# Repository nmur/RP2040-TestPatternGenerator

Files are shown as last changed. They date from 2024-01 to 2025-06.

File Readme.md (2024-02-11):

# RP2040-TestPatternGenerator

This is a simple test pattern generator that runs on the RP2040 microcontroller. It uses the [PicoVGA cmake](https://github.com/codaris/picovga-cmake) library for outputting a 15kHz 240p RGBS signal via a VGA connector. This tool is aimed to be used for rudimentary tests for checking basic CRT TV functionality, not for accurate calibration.  

Its main features are:  
- **Cheap**: Approximately <$15 USD in parts, less if you already have some components or if you want to make a few.
- **Accessible**: Open source. Soldering is easy enough even for a first timer.
- **Small**: Roughly 2x2"/50x50mm in size.
- **Fast**: Boots and changes patterns instantly.
- **Portable**: Very low power draw, works with a powerbank.

[](https://github.com/nmur/RP2040-TestPatternGenerator/assets/8315014/7c5d83b8-fa1e-4127-8eaf-c0302f727538)[](https://github.com/nmur/RP2040-TestPatternGenerator/assets/8315014/ee1879ff-74e5-49d6-872a-809746e85480)

## Limitations

This program can only output colours in the RGB332 space, so each of the three colour channels (Red, Green, and Blue) are represented by 3, 3, and 2 bits, respectively. More information can be found [here](https://github.com/nmur/RP2040-TestPatternGenerator/wiki/Limitations).

## Getting Started

1. [Obtain all the components and assemble the device](https://github.com/nmur/RP2040-TestPatternGenerator/wiki/Assembly).
2. Download the [latest firmware](https://github.com/nmur/RP2040-TestPatternGenerator/releases).
3. Hold the BOOT button on the RP2040 device and connect it to your PC. A file browser window for the device should appear.
4. Drag and drop the `RP2040-TestPatternGenerator.uf2` file onto the device. It should automatically close when completed.

## How to Use

- [Connect the device to your TV](https://github.com/nmur/RP2040-TestPatternGenerator/wiki/Frequently-Asked-Questions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), and connect a USB-C cable for power.
- Press the connected button to cycle through patterns.
- To flash a newer firmware, follow the same firmware installation steps from the [Getting Started](https://github.com/nmur/RP2040-TestPatternGenerator/tree/main?tab=readme-ov-file#getting-started) section. Once the device is installed in an enclosure and the BOOT button is inaccessable, connect the device to your computer, hold the same button for 3 seconds and release. The device will reboot into flash mode.

## Building

1. Generate the make files by running CMake:
~~~
cmake .
~~~

2. Build the project:
~~~
make
~~~

## Acknowledgements

- Miroslav Nemecek (Panda38@seznam.cz) for their [PicoVGA library](https://github.com/Panda381/PicoVGA)
- Wayne Venables (codaris) for their [PicoVGA fork](https://github.com/codaris/picovga-cmake)
- Turi Scandurra (TuriSc) for their [RP2040-Button library](https://github.com/TuriSc/RP2040-Button)

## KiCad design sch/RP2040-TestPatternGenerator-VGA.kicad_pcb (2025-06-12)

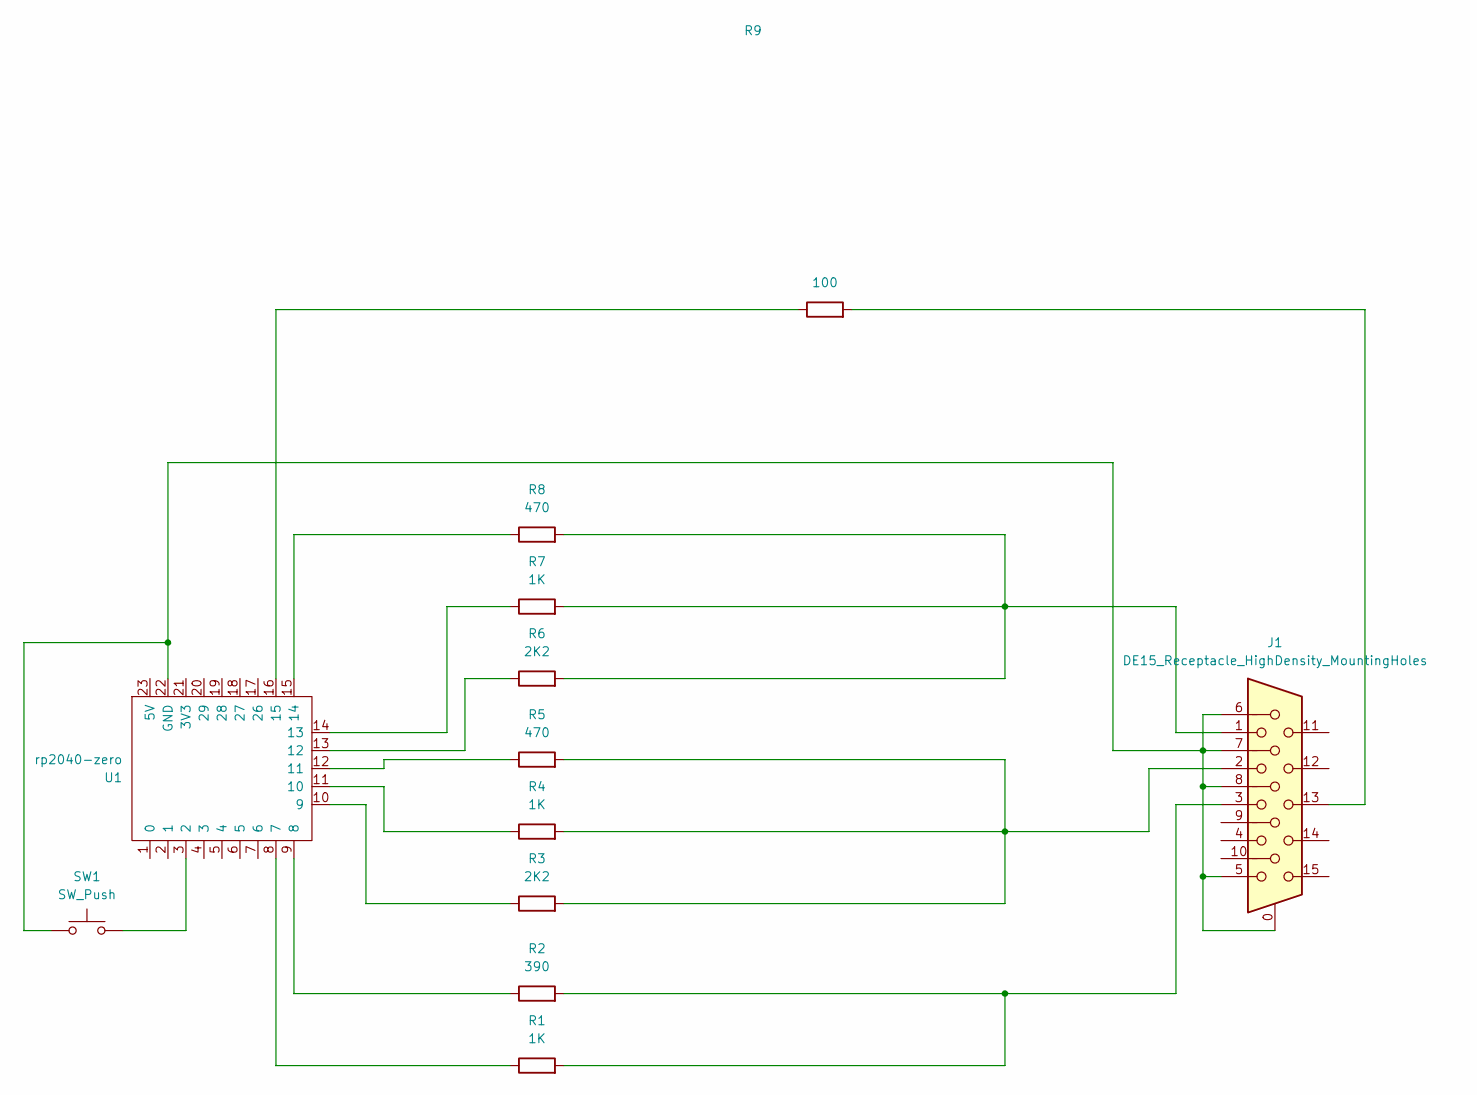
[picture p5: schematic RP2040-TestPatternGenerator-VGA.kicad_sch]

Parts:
J1: DE15_Receptacle_HighDensity_MountingHoles; DSUB-15-HD_Female_Horizontal_P2.29x1.98mm_EdgePinOffset3.03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
R1, R4, R7: 1K; R_Axial_DIN0207_L6.3mm_D2.5mm_P10.16mm_Horizontal
R2: 390; R_Axial_DIN0207_L6.3mm_D2.5mm_P10.16mm_Horizontal
R3, R6: 2K2; R_Axial_DIN0207_L6.3mm_D2.5mm_P10.16mm_Horizontal
R5, R8: 470; R_Axial_DIN0207_L6.3mm_D2.5mm_P10.16mm_Horizontal
R9: 100; R_Axial_DIN0207_L6.3mm_D2.5mm_P10.16mm_Horizontal
SW1: SW_Push; SW_Tactile_SPST_Angled_PTS645Vx58-2LFS
U1: rp2040-zero; rp2040-zero-smd

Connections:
unnamed 0: J1.1, R6.2, R7.2, R8.2; also elsewhere on the board
unnamed 1: J1.2, R3.2, R4.2, R5.2; also elsewhere on the board
unnamed 2: J1.3, R1.2, R2.2; also elsewhere on the board
unnamed 3: J1.13, R9.2; also elsewhere on the board
unnamed: SW1.2, U1.3 (2)
unnamed: R1.1, U1.8 (7)
unnamed: R2.1, U1.9 (8)
unnamed: R3.1, U1.10 (9)
unnamed: R4.1, U1.11 (10)
unnamed: R5.1, U1.12 (11)
unnamed: R6.1, U1.13 (12)
unnamed: R7.1, U1.14 (13)
unnamed: R8.1, U1.15 (14)
unnamed: R9.1, U1.16 (15)
unnamed 14: J1.0, J1.5, J1.6, J1.7, J1.8, SW1.1, U1.22 (GND); also elsewhere on the board

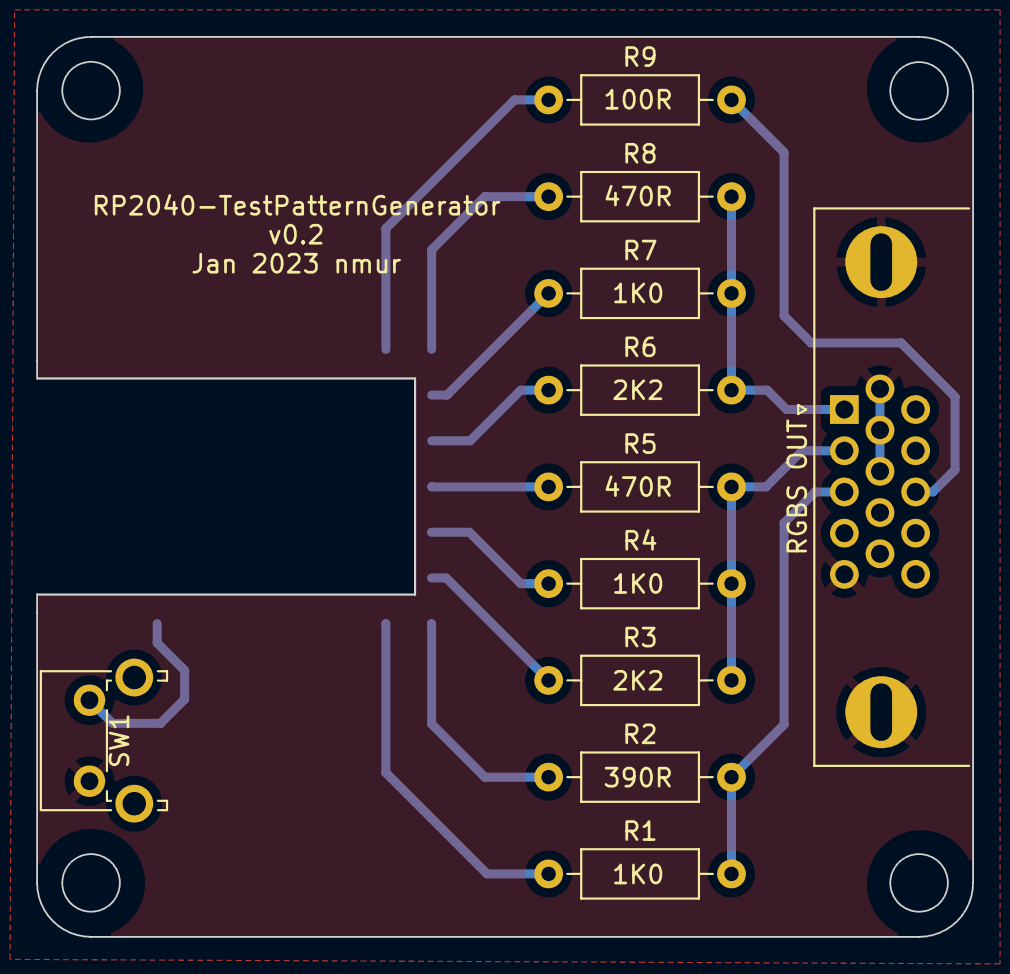
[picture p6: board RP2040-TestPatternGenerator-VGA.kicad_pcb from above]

Board: 2 copper layers, 52.0 x 50.0 mm, 12 parts (1 on the bottom side), 15 nets.

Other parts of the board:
RGBS OUT: DE15_Receptacle_HighDensity_MountingHoles; DSUB-15-HD_Female_Horizontal_P2.29x1.98mm_EdgePinOffset3.03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

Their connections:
unnamed 0: RGBS OUT.1; also elsewhere on the board
unnamed 1: RGBS OUT.2; also elsewhere on the board
unnamed 2: RGBS OUT.3; also elsewhere on the board
unnamed 3: RGBS OUT.13; also elsewhere on the board
unnamed 14: RGBS OUT.0, RGBS OUT.5, RGBS OUT.6, RGBS OUT.7, RGBS OUT.8; also elsewhere on the board

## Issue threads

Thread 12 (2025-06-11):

Schematic and brd files

eimparas, 2025-06-11:
While looking at this project, i failed to spot any `.sch` and .`brd` files (or a pdf could do) for the schematic of this very noice project.  Only the gerber files are uploaded.

Was this intentional ie the creator does not want schematics / board out there or they are simply forgoten?

nmur, 2025-06-12:
Hey, yeah this was an oversight and I likely just forgot to upload the schematic files themselves. He's a screenshot but I'll upload the kicad files too

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

eimparas, 2025-06-12:
Thanks for the immediate response!

I thought so it would be a oversight! Have a nice day.

Closed 2025-06-12.

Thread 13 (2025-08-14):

The razio under resistors selection

baritonomarchetto, 2025-08-14:
Hello, not an issue but an explanation request.
How are the series resistors values selectedfor each color? It clearly has something to do with the color resolution, but I still cannot get the razio.
Thanks!

baritonomarchetto, 2025-08-15:
Thanks for your answer. The "strange" thing to me was the use of different values for the resistor ladder, but perhaps this makes it possible to use one GPIO line at a time instead of three.
A last question: which GPIO did you use for pattern cycling? Reading the code I assumed was #2, but it is already used for a color line.
Thank you very much :)

Closed 2025-08-15.

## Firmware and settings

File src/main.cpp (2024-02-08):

#include "picovga.h"
#include "img/colourbars.h"
#include "img/colourgradients.h"
#include "img/circles.h"
#include "img/grid.h"
#include "img/white.h"
#include "lib/RP2040-Button/button.h"
#include "pico/bootrom.h"

#include <chrono>

#define WIDTH	320		// screen width
#define HEIGHT	240		// screen height

#define GPIO_CYCLE_PATTERN 2

using sys_clock_t = std::chrono::high_resolution_clock;
using time_point_t = std::chrono::time_point<sys_clock_t>;
time_point_t buttonPressTime;

const u8* PatternArray[] = {
	Colour_Bars,
	Grid,
    White,
	Colour_Gradients,
	Circles
};
int PatternArraySize = 4;
int PatternIndex = 0;

ALIGNED u8 Framebuffer[320*240];

sCanvas PatternCanvas;

void initialise_pattern()
{
    // Initialise canvas
    PatternCanvas.img = (u8 *)PatternArray[PatternIndex];
    PatternCanvas.w = WIDTH;
    PatternCanvas.h = HEIGHT;
    PatternCanvas.wb = WIDTH;
    PatternCanvas.format = CANVAS_8;

    // Draw pattern
    DrawImg(&Canvas, &PatternCanvas, 0, 0, 0, 0, WIDTH, HEIGHT);
}

void draw_next_pattern()
{
    PatternIndex = (PatternIndex + 1) % PatternArraySize;
    PatternCanvas.img = (u8 *)PatternArray[PatternIndex];
    DrawImg(&Canvas, &PatternCanvas, 0, 0, 0, 0, WIDTH, HEIGHT);
}

void button_onchange(button_t *button_p){
    button_t *button = (button_t*)button_p;

    if (button->state) {
        // Button release
        // Calculate the duration of the button press
        auto duration = std::chrono::duration_cast<std::chrono::seconds>(sys_clock_t::now() - buttonPressTime).count();

        if (duration >= 3) {
            // Reboot into BOOLSEL for flashing on long press
            reset_usb_boot(0,0);
        }

        return; // Ignore button release.
    }
    else {
        // Button press
        buttonPressTime = sys_clock_t::now();
    }

    draw_next_pattern();
}

int main()
{
	// Initialize video mode
	Video(DEV_NTSC, RES_QVGA, FORM_8BIT, Framebuffer);

    initialise_pattern();

    // Button handling
	create_button(GPIO_CYCLE_PATTERN, button_onchange);

	while (true)
	{
        sleep_ms(100);
	}
}

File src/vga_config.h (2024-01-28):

// ****************************************************************************
//                                 
//                            VGA configuration
//
// ****************************************************************************

// === Configuration
#define LAYERS		4	// total layers 1..4 (1 base layer + 3 overlapped layers)
#define SEGMAX		8	// max. number of video segment per video strip (size of 1 sSegm = 28 bytes)
#define STRIPMAX	8	// max. number of video strips (size of 1 sStrip = sSegm size*SEGMAX+4 = 228 bytes)
				// size of sScreen = sStrip size*STRIPMAX+4 = 1828 bytes

#define MAXX		640	// max. resolution in X direction (must be power of 4)
#define MAXY		480	// max. resolution in Y direction

#define MAXLINE		700	// max. number of scanlines (including sync and dark lines)

// === Scanline render buffers (800 pixels: default size of buffers = 2*4*(800+8+800+24)+800 = 13856 bytes
//    Requirements by format, base layer 0, 1 wrap X segment:
//	GF_GRAPH8 ... control buffer 16 bytes
//	GF_TILE8 ... control buffer "width"+8 bytes
//	GF_TILE16 ... control buffer "width/2"+8 bytes
//	GF_TILE32 ... control buffer "width/4"+8 bytes
//	GF_TILE64 ... control buffer "width/8"+8 bytes
//	GF_PROGRESS ... control buffer 24 bytes
//	other formats: data buffer "width" bytes, control buffer 16 bytes
#define DBUF0_MAX	(MAXX+8)	// max. size of data buffer of layer 0
#define CBUF0_MAX	((MAXX+24)/4)	// max. size of control buffer of layer 0

//    Requirements by format, overlapped layer 1..3:
//	LAYERMODE_SPRITE* ... data buffer "width"+4 bytes, control buffer 24 bytes
//	LAYERMODE_FASTSPRITE* ... data buffer "width"+4 bytes, control buffer up to "width*2"+16 bytes
//	other formats ... data buffer 4 bytes, control buffer 24 bytes
#define DBUF1_MAX	(MAXX+8)	// max. size of data buffer of layer 1
#define CBUF1_MAX	((MAXX+24)/4)	// max. size of control buffer of layer 1

#define DBUF2_MAX	(MAXX+8)	// max. size of data buffer of layer 2
#define CBUF2_MAX	((MAXX+24)/4)	// max. size of control buffer of layer 2

#define DBUF3_MAX	(MAXX+8)	// max. size of data buffer of layer 3
#define CBUF3_MAX	((MAXX+24)/4)	// max. size of control buffer of layer 3

#if LAYERS==1
#define	DBUF_MAX	DBUF0_MAX	// max. size of data buffer
#define	CBUF_MAX	CBUF0_MAX	// max. size of control buffer
#elif LAYERS==2
#define	DBUF_MAX	(DBUF0_MAX+DBUF1_MAX)	// max. size of data buffer
#define	CBUF_MAX	(CBUF0_MAX+CBUF1_MAX)	// max. size of control buffer
#elif LAYERS==3
#define	DBUF_MAX	(DBUF0_MAX+DBUF1_MAX+DBUF2_MAX)	// max. size of data buffer
#define	CBUF_MAX	(CBUF0_MAX+CBUF1_MAX+CBUF2_MAX)	// max. size of control buffer
#elif LAYERS==4
#define	DBUF_MAX	(DBUF0_MAX+DBUF1_MAX+DBUF2_MAX+DBUF3_MAX) // max. size of data buffer
#define	CBUF_MAX	(CBUF0_MAX+CBUF1_MAX+CBUF2_MAX+CBUF3_MAX) // max. size of control buffer
#else
#error Unsupported number of layers!
#endif

// === VGA port pins
//	GP0 ... VGA B0 blue
//	GP1 ... VGA B1
//	GP2 ... VGA G0 green
//	GP3 ... VGA G1
//	GP4 ... VGA G2
//	GP5 ... VGA R0 red
//	GP6 ... VGA R1
//	GP7 ... VGA R2
//	GP8 ... VGA SYNC synchronization (inverted: negative SYNC=LOW=0x80, BLACK=HIGH=0x00)
#define VGA_GPIO_FIRST	7	// first VGA GPIO
#define VGA_GPIO_NUM	9	// number of VGA GPIOs, including HSYNC and VSYNC
#define VGA_GPIO_OUTNUM	8	// number of VGA color GPIOs, without HSYNC and VSYNC
#define VGA_GPIO_LAST	(VGA_GPIO_FIRST+VGA_GPIO_NUM-1)	// last VGA GPIO
#define VGA_GPIO_SYNC	15	// VGA SYNC GPIO

// VGA PIO and state machines
#define VGA_PIO		pio0	// VGA PIO
#define VGA_SM0		0	// VGA state machine of base layer 0
#define VGA_SM1		1	// VGA state machine of overlapped layer 1
#define VGA_SM2		2	// VGA state machine of overlapped layer 2
#define VGA_SM3		3	// VGA state machine of overlapped layer 3
#define VGA_SM(layer)	(VGA_SM0+(layer)) // VGA state machine of the layer

#if LAYERS==1
#define VGA_SMALL	B0	// mask of all state machines
#elif LAYERS==2
#define VGA_SMALL	(B0+B1) // mask of all state machines
#elif LAYERS==3
#define VGA_SMALL	(B0+B1+B2) // mask of all state machines
#elif LAYERS==4
#define VGA_SMALL	(B0+B1+B2+B3) // mask of all state machines
#else
#error Unsupported number of layers!
#endif

// VGA DMA
#define VGA_DMA		0		// VGA DMA base channel
#define VGA_DMA_CB0	(VGA_DMA+0)	// VGA DMA channel - control block of base layer
#define VGA_DMA_PIO0	(VGA_DMA+1)	// VGA DMA channel - copy data of base layer to PIO (raises IRQ0 on quiet)
#define VGA_DMA_CB1	(VGA_DMA+2)	// VGA DMA channel - control block of overlapped layer 1
#define VGA_DMA_PIO1	(VGA_DMA+3)	// VGA DMA channel - copy data of overlapped layer 1 to PIO
#define VGA_DMA_CB2	(VGA_DMA+4)	// VGA DMA channel - control block of overlapped layer 1
#define VGA_DMA_PIO2	(VGA_DMA+5)	// VGA DMA channel - copy data of overlapped layer 2 to PIO
#define VGA_DMA_CB3	(VGA_DMA+6)	// VGA DMA channel - control block of overlapped layer 1
#define VGA_DMA_PIO3	(VGA_DMA+7)	// VGA DMA channel - copy data of overlapped layer 3 to PIO
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

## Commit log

2024-01-28 edited pin configuration for optimal layout for Waveshare RP2040-Zero
2024-01-28 added the RP2040-Button library
2024-01-28 added basic button handling (just displays text on screen)
2024-01-28 added grid pattern and code to switch to grid on button press (grid image was converted incorrectly)
2024-01-28 updated readme with RP2040-Button acknowledgements
2024-01-29 added v0.1 gerber files (untested IRL)
    [RP2040-TestPatternGenerator-B_Cu.gbl, RP2040-TestPatternGenerator-B_Mask.gbs, RP2040-TestPatternGenerator-B_Paste.gbp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]
2024-01-29 reworked the included test patterns, and added functionality to cycle through them
    [main.cpp]
2024-01-30 new gerber files for smaller PCB
    [RP2040-TestPatternGenerator-B_Cu.gbl, RP2040-TestPatternGenerator-B_Mask.gbs, RP2040-TestPatternGenerator-B_Paste.gbp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]
2024-01-30 added long press handling to reboot into flash mode
    [main.cpp]
